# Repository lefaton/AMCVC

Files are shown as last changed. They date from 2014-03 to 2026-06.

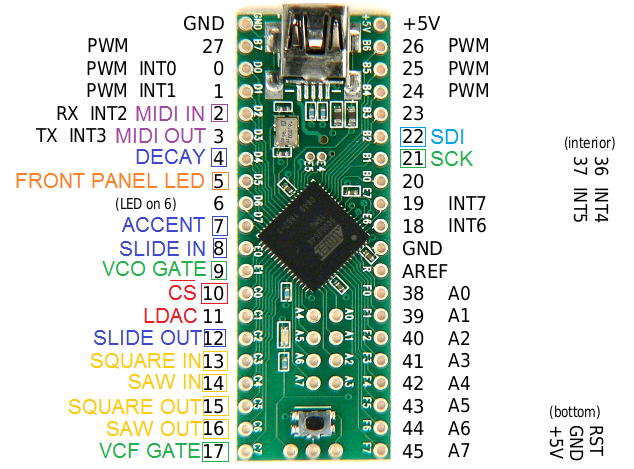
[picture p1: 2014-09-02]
Documents/Teensy 1.0++ pinout.png

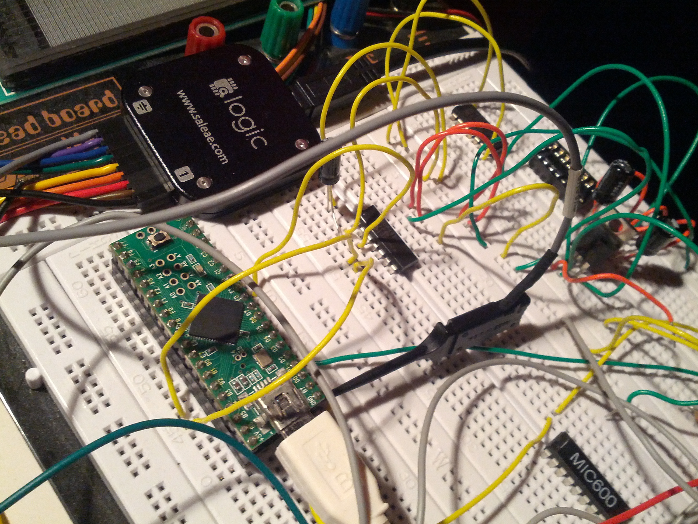
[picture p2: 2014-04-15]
Documents/Pictures/prototyping_phase3.jpg

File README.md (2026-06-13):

# AMCVC — Arduino MIDI to CV Converter

A MIDI-to-CV daughter board designed to drive the [x0x-heart](http://www.openmusiclabs.com/projects/x0x-heart/) — an open-source clone of the Roland TB-303 bass synthesizer engine. The board sits between a MIDI source and the x0x-heart, converting MIDI note and CC messages into analog control voltages (CV) and digital gate/control signals.

Built around a **Teensy++ 1.0** microcontroller and a **MCP4922 12-bit dual DAC** via SPI. The firmware is written as an Arduino sketch.

> **Status:** The firmware is working and was successfully tested on a prototype. The
> schematic and board netlist have been corrected (2026 revision) — the two changed nets
> (`~SHDN`, `~LDAC`) still need re-routing in Eagle plus a DRC pass before fabrication.

---

## Context — What Is the x0x-heart?

The [x0x-heart](http://www.openmusiclabs.com/projects/x0x-heart/) is an open hardware recreation of the Roland TB-303 synthesizer core. It exposes CV and gate inputs for pitch, filter cutoff, and a set of digital control lines (decay, accent, slide in, slide out) that replicate the 303's characteristic playing articulations.

The AMCVC board plugs into those inputs and translates MIDI messages into the signals the x0x-heart expects, making it possible to sequence and play the 303 engine from any standard MIDI controller or DAW.

---

## Hardware Overview

### Microcontroller — Teensy++ 1.0

The [Teensy++ 1.0](https://www.pjrc.com/teensy/) is a compact USB-capable AVR microcontroller board (AT90USB1286). It runs the Arduino-compatible MIDI library and handles SPI communication with the DAC. A reference pinout is included in `Documents/Teensy 1.0++ pinout.png`.

### DAC — MCP4922 (12-bit, dual-channel, SPI)

The [MCP4922](https://www.microchip.com/MCP4922) is a 12-bit dual-output DAC communicating over SPI. It provides two independent CV outputs:

| Channel | Purpose | Constant | Driven by |
|---|---|---|---|
| A (0) | VCO pitch | `VCO_DAC_ID = 0` | MIDI note number  |
| B (1) | VCF cutoff  | `VCF_DAC_ID = 1` | MIDI CC 74 |

SPI is configured MSB-first, SPI Mode 0. The 16-bit command word sent to the MCP4922 is:

```
Bit 15   : A/B   — channel select (0 = channel A / VCO, 1 = channel B / VCF)
Bit 14   : BUF   — input buffer (0 = unbuffered)
Bit 13   : /GA   — gain select (1 = 1× gain, 0–Vref)
Bit 12   : /SHDN — output enable (1 = active)
Bits 11–0: 12-bit DAC value
```

`WriteDAC(channel, value)` builds the word per channel: it ORs in `0x3000` (bits 13
and 12 → 1× gain, output active) and sets bit 15 from the channel argument, so both
the VCO (channel A) and VCF (channel B) outputs are addressable.

### MIDI Isolation — 6N138 Optocoupler

MIDI input is electrically isolated using a [6N138](Documents/Datasheets/6N138.pdf) high-speed optocoupler, following the standard MIDI electrical interface specification. This prevents ground loops between the MIDI source and the synth circuitry.

---

## Pin Assignments (Teensy++ 1.0)

| Pin | Direction | Function |
|-----|---|---|
| 2 | INPUT | MIDI input (via 6N138) |
| 4 | OUTPUT | Decay control (x0x-heart) |
| 5 | OUTPUT | Front panel LED |
| 6 | OUTPUT | Board LED |
| 7 | OUTPUT | Accent control (x0x-heart) |
| 8 | OUTPUT | Slide In control |
| 9 | OUTPUT | VCO Gate |
| 10  | OUTPUT | SPI CS (MCP4922 chip select) |
| 11  | OUTPUT | SPI LDAC (DAC latch) |
| 12  | OUTPUT | Slide Out control |
| 13  | INPUT | Square wave input (x0x) |
| 14  | INPUT | Saw wave input (x0x) |
| 15  | OUTPUT | Square wave output |
| 16  | OUTPUT | Saw wave output |
| 17  | OUTPUT | VCF Gate |

---

## MIDI Configuration

```cpp
const int MIDIChannel = 3;  // MIDI channel to listen on
```

The sketch listens on MIDI channel 3 only — `MIDI.begin(MIDIChannel)` filters out
all other channels at the library level. To change channel, edit this constant and
re-upload.

---

## MIDI Note to CV Conversion

### Pitch (VCO)

The firmware converts MIDI note numbers to a 12-bit DAC value using a linear mapping:

```cpp
const float VCO_CV_step     = 68.25;  // DAC counts per semitone
const int   MIDI_Min_Note   = 24;     // C1 (lowest accepted note)
const int   MIDI_Max_Note   = 84;     // C6 (highest accepted note)
const int   MIDI_Start_Offset = 24;   // note 24 maps to DAC value 0
const int   VCO_CV_Offset   = 0;      // global tuning offset in semitones
```

Conversion formula:

```
convertedVal = (note + VCO_CV_Offset - MIDI_Start_Offset) × VCO_CV_step
```

**Example values:**

| MIDI Note | Note Name | DAC value | Approx. CV |
|---|---|---|---|
| 24 | C1 | 0 | 0 V |
| 36 | C2 | 819 | ~1 V |
| 48 | C3 | 1638 | ~2 V |
| 60 | C4 (middle C) | 2457 | ~3 V |
| 72 | C5 | 3276 | ~4 V |
| 84 | C6 | 4095 | ~5 V |

The 60-semitone range (C1–C6) maps to 0–4095, giving **1V/octave** when the DAC reference voltage is 5V. Fine-tune `VCO_CV_step` if your VCO has a different V/oct scaling. The full lookup table is in `Documents/table_midi_cv.xlsx`.

### Gate

| MIDI event | Gate pins | Logic |
|---|---|---|
| Note On (velocity > 0)  | pin 9 + pin 17 | LOW (active)  |
| Note Off / velocity = 0 | pin 9 + pin 17 | HIGH (off) |

The x0x-heart gates are active-low. Both the VCO gate (pin 9) and VCF gate (pin 17)
are driven together.

### Note priority (monophonic note stack)

The firmware is monophonic but tracks held notes in a small stack (up to 8 notes):

- **Note On** pushes the note and plays it immediately (last-note priority).
- **Note Off** removes the note from the stack. Releasing a note that is *not* the
  one currently sounding does **not** cut the gate — it just leaves the stack.
- Releasing the sounding note falls back to the most recently held note still down;
  the gate only closes when no notes remain.

This makes legato/overlapping play behave the way a hardware mono synth does.

### VCF cutoff (CC 74)

MIDI **CC 74** (the standard "brightness"/cutoff controller) drives the VCF on DAC
channel B. Values 0–127 are mapped linearly to the full 12-bit range (0–4095).

---

## TB-303 Specific CC Messages

The x0x-heart exposes four articulation controls specific to the TB-303 playing style. The firmware maps MIDI CC messages to digital lines:

| CC  | Hex | Function | Effect when value > 100 |
|-----|---|---|---|
| 99  | 0x63  | Decay | Pin 4 LOW (decay enabled) |
| 100 | 0x64  | Accent | Pin 7 LOW (accent enabled) |
| 101 | 0x65  | Slide In | Pin 8 LOW (slide in enabled) |
| 102 | 0x66  | Slide Out  | Pin 12 LOW (slide out enabled) |

A CC value strictly above 100 (`triggerLimit = 0x64`) activates the control; 100 or
below deactivates it. CC 74 (cutoff) is the exception — it is a continuous value, not
a trigger (see [VCF cutoff](#vcf-cutoff-cc-74) above).

**Slide mutual exclusion:** Slide In and Slide Out are mutually exclusive — activating one automatically cancels the other, mirroring the 303's hardware behavior.

---

## Wave Pass-Through

The x0x-heart outputs both a **square wave** and a **sawtooth wave**. The AMCVC board reads these on pins 13/14 and re-outputs them on pins 15/16 every loop cycle, acting as a signal buffer:

```cpp
digitalWrite(sawWaveOut_Pin,    digitalRead(sawWaveIn_Pin));
digitalWrite(squareWaveOut_Pin, digitalRead(squareWaveIn_Pin));
```

---

## Repository Structure

```
sketch_MIDI_to_CV/
  sketch_MIDI_to_CV.ino       ← Arduino firmware (upload this to Teensy)

Documents/
  table_midi_cv.xlsx          ← Full MIDI note to CV conversion table
  Teensy 1.0++ pinout.png     ← Teensy++ 1.0 pin reference diagram
  x0x Heart - tb-303.fpd     ← Front panel design (Frontpanel Designer)
  x0xheartmanual.pdf          ← x0x-heart complete manual

  Eagle/
    *.sch   ← Circuit schematic (Eagle CAD) — use this as reference
    *.brd   ← PCB layout (Eagle CAD) ⚠️ 2 nets unrouted after netlist fix

  Datasheets/
    MCP4922.pdf               ← 12-bit dual DAC datasheet
    6N138.pdf                 ← MIDI optocoupler datasheet
```

> ⚠️ **PCB note:** The Eagle netlist bugs (`~SHDN` grounded, `~LDAC` floating) are fixed in
> both `.sch` and `.brd`. On the board these two nets are now **unrouted airwires** — open in
> Eagle, run ERC/forward-annotation, route `~SHDN` (→ +5V) and `~LDAC` (→ MCU pin 11), then DRC
> before sending to a fab.

---

## Setup

### Arduino Libraries Required

- **MIDI Library** — [FortySevenEffects/arduino_midi_library](https://github.com/FortySevenEffects/arduino_midi_library)
- **SPI** — built into the Arduino/Teensy core

### Upload Steps

1. Install [Teensyduino](https://www.pjrc.com/teensy/teensyduino.html)
2. Select board: **Teensy++ 1.0**
3. Set USB Type to **Serial** (for debug output)
4. Open `sketch_MIDI_to_CV/sketch_MIDI_to_CV.ino`
5. Upload

MIDI runs at 31250 baud on the hardware UART. Debug output runs at 57600 baud on USB Serial.

---

## Known Issues & Future Work

- **Two nets need routing** — after the 2026 netlist fixes, `~SHDN` and `~LDAC` are
  unrouted airwires on the board (see below); they must be routed in Eagle before a fab run
- **Monophonic only** — no chord support; the note stack gives last-note priority but a single voice
- **Firmware untested since revision** — the 2026 firmware changes (dual-channel DAC,
  VCF CC 74, note stack, channel filtering, non-blocking LED) have not yet been flashed
  and verified on hardware

### Fixed in the 2026 revision

**Schematic / PCB netlist** (corrected in both `.sch` and `.brd`, verified by netlist
re-parse — Eagle ERC/DRC still required):

- **DAC `~SHDN` no longer grounded** — pin 9 moved from `AGND` to `+5V`. It was tied to
  ground, which held both DAC outputs in permanent hardware shutdown (root cause of "no CV out")
- **DAC `~LDAC` now connected** — pin 8 wired to MCU pin 11; both were floating, so the
  latch line never transferred values to the outputs
- **VCF output labelled** — the `VOUTB` connector pad was renamed `UNUSED` → `VCF_CUTOFF`

> On the board, the two changed nets (`~SHDN`, `~LDAC`) are left as **airwires** — the old
> AGND copper at pad 9 was removed so nothing shorts. Open the `.brd` in Eagle, run
> ERC/forward-annotation, route the two airwires, then DRC.

**Firmware:**

- **VCF CV** — DAC channel B is now driven from MIDI CC 74
- **MIDI channel filtering** — `MIDI.begin(MIDIChannel)` replaces `MIDI_CHANNEL_OMNI`
- **Gate latency** — the LED blink is non-blocking, so Note On no longer delays the DAC write by 25 ms
- **Stuck-note edge cases** — a note stack prevents Note Off of an inactive note from cutting the gate

---

## License

GNU General Public License v2.0 — see [LICENSE](LICENSE).

If you use or build on this project, please mention [github.com/utopikprod](https://github.com/utopikprod/) as a reference.

---

## References

- [x0x-heart (Open Music Labs)](http://www.openmusiclabs.com/projects/x0x-heart/)
- [Teensy++ 1.0 (PJRC)](https://www.pjrc.com/teensy/)
- [MCP4922 datasheet](Documents/Datasheets/MCP4922.pdf)
- [6N138 optocoupler datasheet](Documents/Datasheets/6N138.pdf)
- [MIDI electrical specification](https://www.midi.org/specifications-old/item/midi-din-electrical-specification)

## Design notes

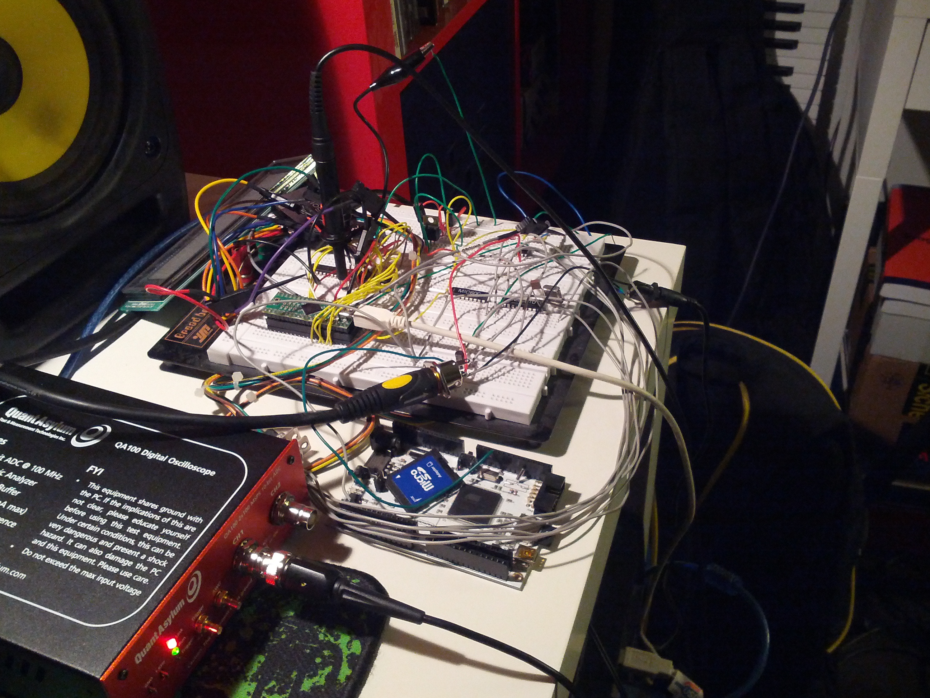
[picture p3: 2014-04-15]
Documents/Pictures/prototyping_phase2.jpg

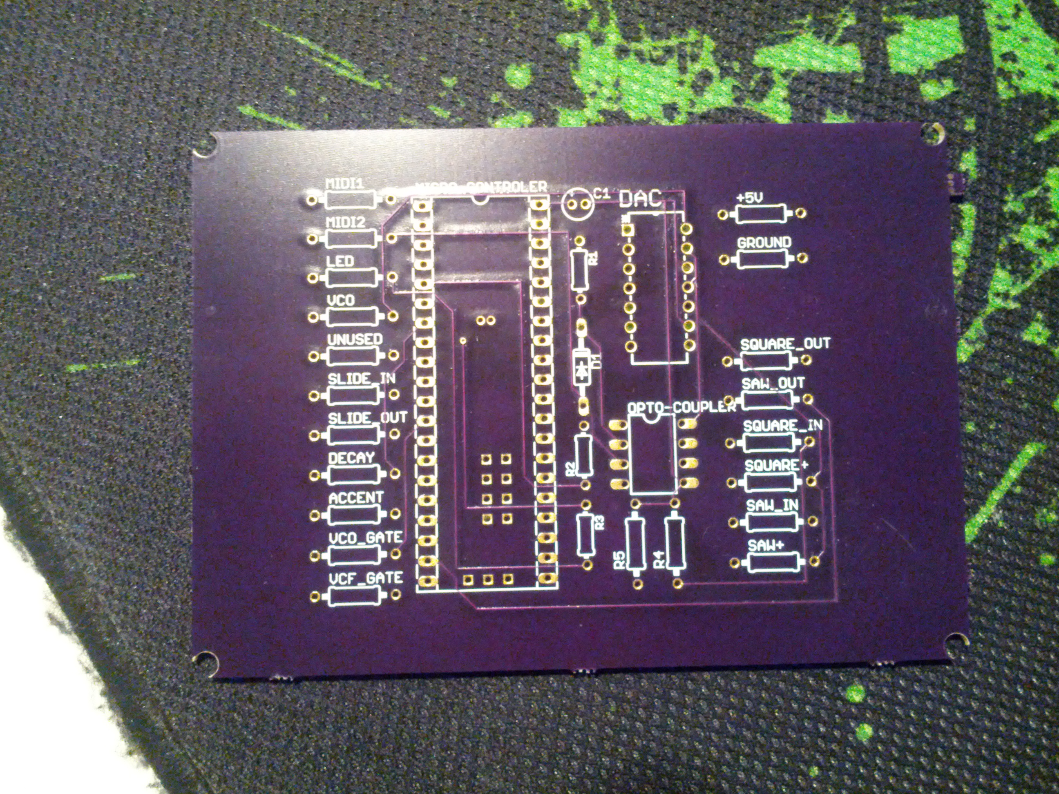
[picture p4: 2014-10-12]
Documents/Pictures/board_1.jpg

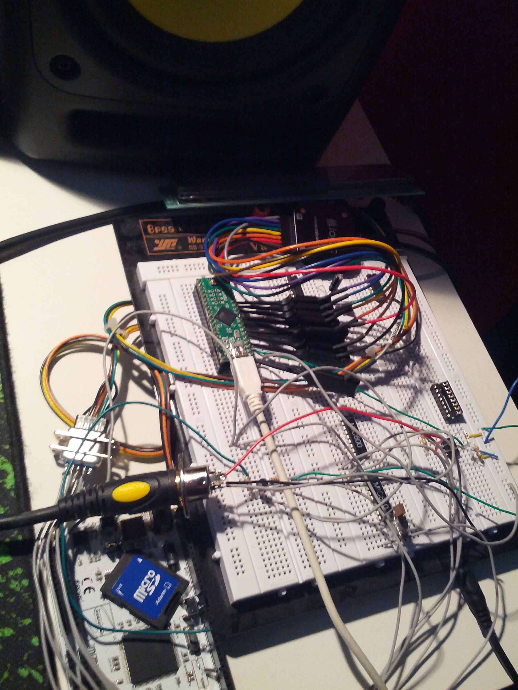
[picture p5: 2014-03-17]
Documents/Pictures/prototyping_phase1.jpg

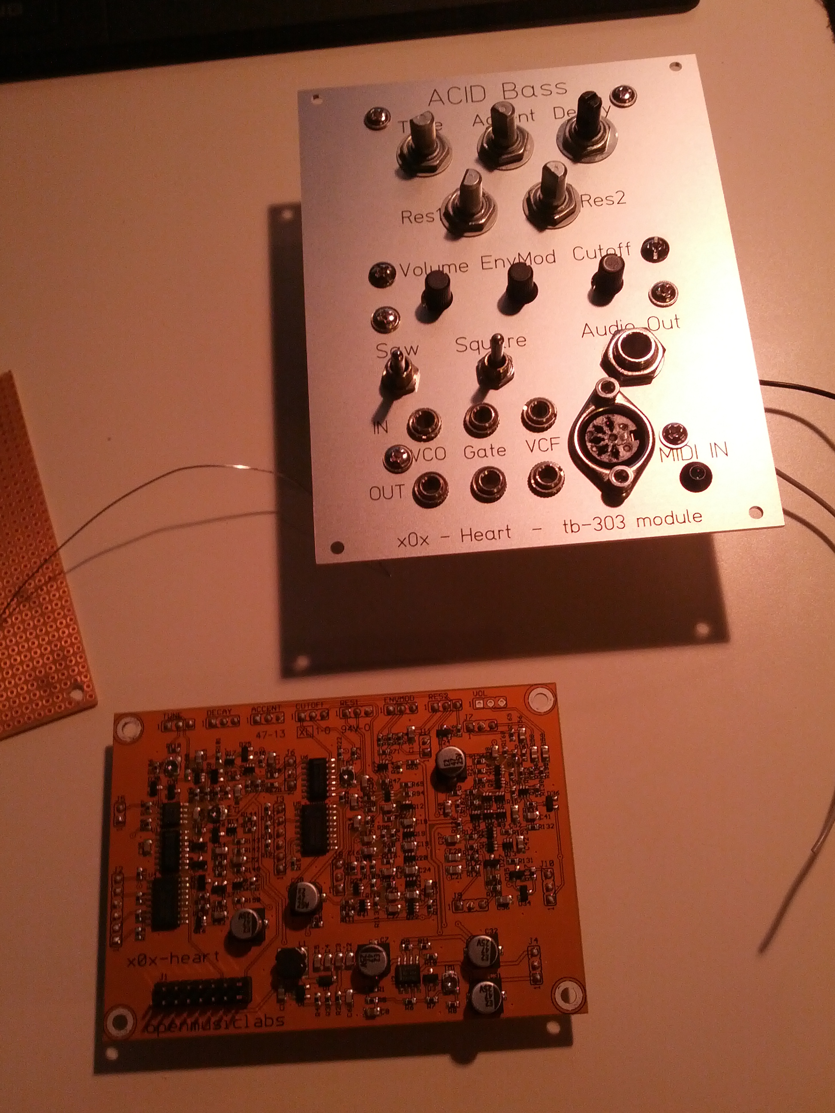
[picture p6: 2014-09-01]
Documents/Pictures/prototyping_phase4.jpg

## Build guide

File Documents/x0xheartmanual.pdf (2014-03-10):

# x0x-heart User Manual

Please read this document carefully before building up your synth. The x0x-heart does not come with any pots or control interface, so you will have to add parts to create a working synthesizer. It is possible to damage the x0x-heart if improper voltages are applied, so be sure to verify everything is in order before powering up your circuit. NOTE: power-supply voltage is 5VDC MAX!!

### 1. Overview:

Below is a picture of the x0x-heart board:

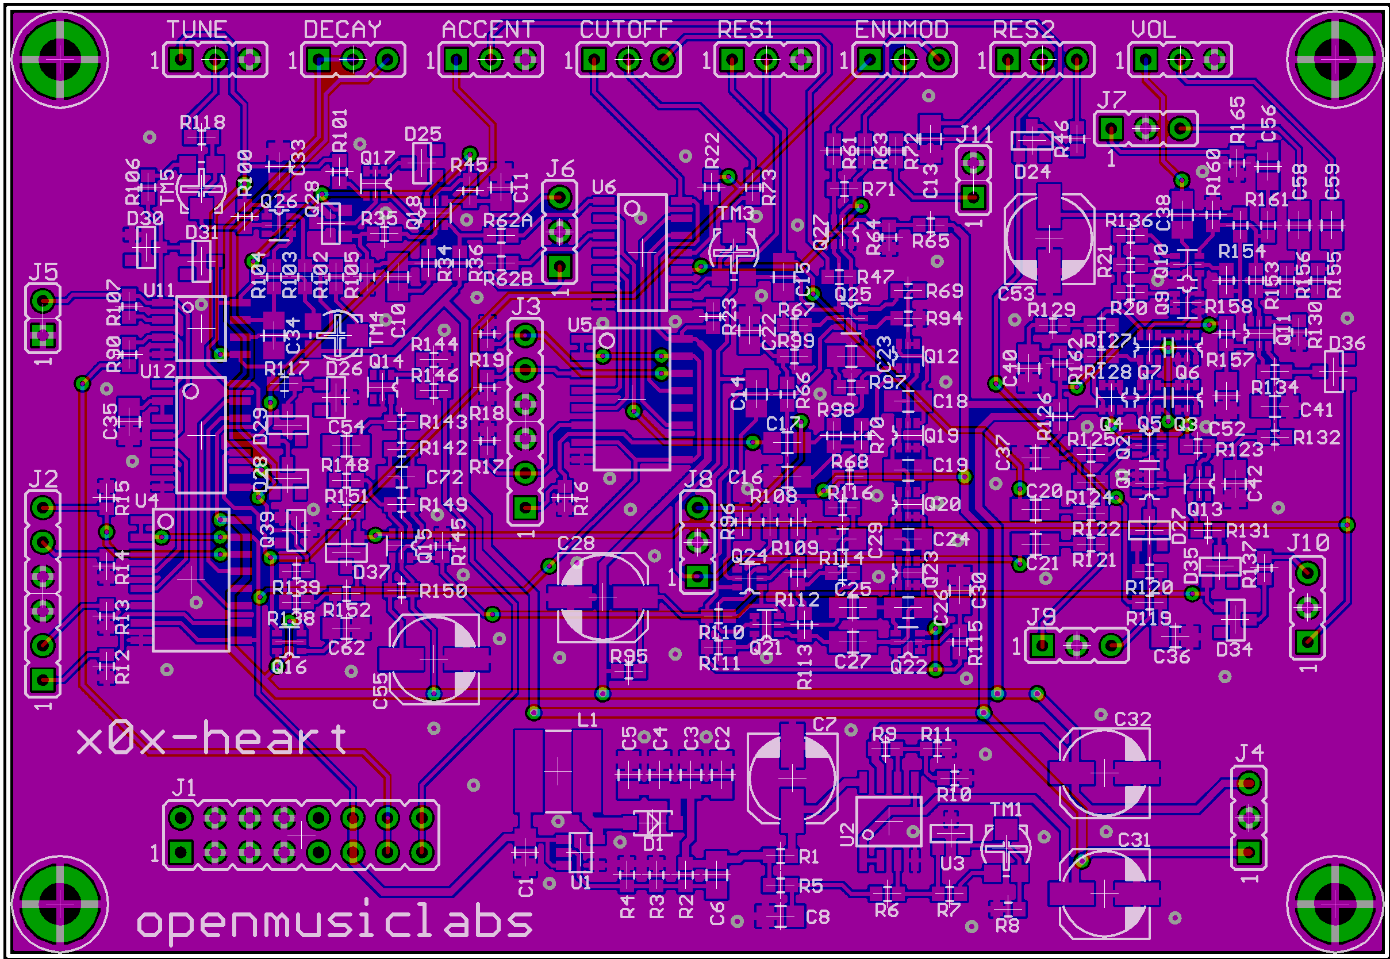
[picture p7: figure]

There are 8 headers for potentiometers, and 11 headers for control inputs and outputs. There are also 4 on-board potentiometers for tuning the power-supply, VCO, and VCF. The rest of this document will explain how to tune the x0x-heart, what all of the headers connect to, and how to interface with them. For all headers, pin1 has a square pad, and is labeled with a 1.

### 2. Tuning

The x0x-heart has 4 SMT trim pots, which require a small phillips screwdriver to adjust. TM1 adjusts the 5.333V supply, TM5 and TM4 adjust the VCO CV response, and TM3 adjusts the VCF cutoff frequency. These trim pots are meant to be turned a few times to get the setting right, and then left alone. They can only handle a few rotations, so do not use them as control inputs. These tuning procedures are best done after you have wired everything up, so that the operating currents are in their normal ranges. You should also let the x0x-heart warm up a bit before performing any calibration.

The 5.333V adjust was used on the original 303 to set the DAC control voltage for the VCO CV generator. Although this is not required on the x0x-heart, as CVs are not generated internally, the 5.333V supply determines how the x0x-heart sounds, so you are welcome to tune this to taste. To set it, turn TM1 while monitoring the output voltage on pin1 of J4 (5.333V is standard).

The x0x-heart uses a switching power-supply and resistive filter to replicate the 303 power-supply. And, just like the original, it sometimes droops under heavy load. Setting TM1 to 5.333V should cause only occasional drooping; going higher than that increases how often this happens, and going lower can eliminate it. The drooping only occurs on the 12V line, and usually only on accented notes. Adding extra circuitry which runs off the 12V line also increases the probability of this happening.

If the droop is not desired, solder a resistor in parallel with R4 and R3. A value between 47k and 100k should do the trick. The lower the resistor value, the less likely it will be to droop. Do not use a value below 12k, as this could hurt the regulator.

The VCO CV adjust is best done by first adjusting the CV width, and then adjusting the offset. This is usually set to 1V/octave, but can be set to any other value within the limits of the device. Set the TUNE knob to mid-position, and alternate between a 1V and 2V CV at the CV input (J1 - pin13,14), and monitor the audio output with an oscilloscope or guitar tuner. Adjust TM5 until the 1V and 2V signals produce tones that are exactly 1 octave apart. Next, adjust the CV offset by turning TM4 until a 2V signal produces a note 2 octaves below middle C (65.4Hz). Your x0x-heart should now be in tune.

The VCF cutoff adjust is a matter of taste. It modifies the exact range that the envelope modulation sweeps through. The 303 manual suggests setting it as follows: Set the CUTOFF knob to center, the waveform to saw, RES1 and RES2 knobs full clockwise, and the ENVMOD, DECAY, and ACCENT knobs full counterclockwise. Apply a 2V CV to the VCO (65.4Hz) and monitor the VCF output (J8 - pin1) on an oscilloscope. The ripples on the saw wave should be spaced at 2ms. If you don't have an oscilloscope, listen for a 500Hz tone on top of the 65.4Hz tone.

### 3. Potentiometers:

The potentiometers all have the 'top' of the pot at pin1, the wiper at pin2, and the 'bottom' at pin3. The 'top' is the side of the pot which is full clockwise. To find out which pins on your pot go where, turn the pot full clockwise, and measure the resistance between the wiper and the 2 other pins. One pin will measure the full resistance of the pot, and the other will measure 0ohms. The side which is 0ohms goes to pin1.

The following table lists the resistance values of the pots:

TUNE | 50kB
DECAY | 1MA
ACCENT | 50kB
CUTOFF | 50kA
RES1 | 50kB
ENVMOD | 50kA
RES2 | 50kB
VOL | 50kA

The only odd thing about the pots, is that the resonance pot is a dual pot. But, the 2 independent parts of the resonance pot are broken out to 2 different headers: RES1 and RES2. RES1 is the feedback pot in the filter, and controls the actual resonance. RES2 controls the amount the accent affects the cut-off frequency. If you are wiring these as 2 separate pots, you may choose to wire RES2 backwards, as turning RES2 more clockwise would normally decrease the affect the accent has on the cut-off frequency.

### 4. J1 - Eurorack header:

All of the pins are doubled up on the Eurorack header (i.e. pin1 and pin2 shorted, pin3 and pin4 shorted).

The following table lists the connections on Eurorack header:

pin1,2 | no connection
pin3,4 | ground
pin5,6 | ground
pin7,8 | ground
pin9,10 | no connection
pin11,12 | Power in, 5VDC MAX!!
pin13,14 | VCO CV in
pin15,16 | GATE in

The Power in connection goes straight to a switching power-supply. This input can work as low as 3.3VDC, and as high as 5VDC. The lower limit is actually set by the level shifter chips, which are not guaranteed to work below 3.3V (although will probably work at 3V). If you want to operate at lower voltages, you can cut some traces and power the level shifters from another bus. The voltage regulator can work down to 1.8VDC, but is not very reliable below 2.7VDC because the inductor and capacitors are optimized for 5VDC.

The high limit is set by the destructive voltage on the switching regulator (actually 6V, but best not to tempt fate). The switching regulator IC can be easily destroyed by over voltage, so be certain that there is no more than 5VDC on pin11 or pin12 of J1! Measure with a multimeter before connecting for the first time.

If you do not have a 5VDC supply, you can easily create one with a 7805 regulator. This will also act as input over-voltage protection. There is no input protection on the circuit as there wasn't a good way of doing this cheaply while keeping the input current consumption down. If you are running the x0x-heart off of a battery, you may want to put a high current diode in parallel or series with the input, to protect against reversed battery connections.

The x0x-heart consumes around 50mA from a 5V supply. This value goes up as the voltage goes down, so a 3V supply will require 85mA.

The VCO CV in connection goes through a 220k resistor to the slide/buffer circuitry. This can handle inputs from 0V to 12V, and is fairly tolerant of over/under-voltage conditions. The input can be tuned within a certain range, but is optimized for 1V/octave. CV inputs above 5V might start getting out of tune, as the original 303 was not designed for CVs above this range. The x0x-heart will normally not produce any sound unless there is a CV applied (the CV drifts out of range).

The Gate in connects to the base of transistor through a 22k resistor. It can accept 0V to 12V in, and is tolerant of over/under-voltage conditions. A 5V signal is preferred, as this is used in the original 303, and other voltages might affect the timing slightly (although probably not noticeably). A high level voltage turns on the gate, and 0V turns off the gate.

### 5. J2 - Digital control input 1:

This header controls the slide, accent, and decay circuitry. All of these pins are inputs, and are 12V tolerant. They are normally pulled low, so if there is no input connection, all of the controls will be off. The inputs go directly to the CD40109 level shifters, which use the Power in voltage as their logic level. Using a logic level lower than the Power in voltage is not guaranteed to work. You can use voltages higher than Power in, but the input pins will draw more current. You should only send digital signals to these pins, as slow transition times will cause the device to draw significantly more power, and might cause the x0x-heart to temporarily stop functioning.

pin1 | slide input control in
pin2 | slide output control in
pin3 | ground
pin4 | ground
pin5 | decay control in
pin6 | accent control in

The Slide input control in connects the slide capacitor to the input CV, and enables slid notes. A logic level high signal engages the slide, and 0V disengages the slide.

The Slide output control in connects the slide capacitor to the output of the CV buffer. This transfers the current CV level to the slide capacitor, so that new notes slide from the old value to the new one. A logic level high signal connects the capacitor, and 0V disengages the capacitor.

To replicate original 303 behaviour, these 2 slide signals must always be opposite of one another. So when one is high, the other must be a 0V, and vice-versa. The reason why this was not hard-wired this way, is that unique slide effects can be made by having independent control of the 2 slide lines. It is not advisable to turn both slide control inputs on at the same time. This will cause the CV buffer to become unstable and no longer respond to the input CV. The device probably won't be harmed under that condition, but it's not guaranteed.

One effect worth trying, is to only using the Slide input control, and pulse width modulate (PWM) the signal. This will engage the slide capacitor for a smaller percentage of the time, effectively increasing its value, and increasing the slide time. This slide time is then determined by the PWM value.

The Decay control in shorts out the DECAY pot, and reduces the decay time to its minimum value. A high level engages the short, and a 0V signal gives control back to the pot. Using a PWM signal on this control line will allow for digitally controlled decay times, as long as the DECAY pot is set to its longest value. In the 303, the decay control and accent control are tied together, so whenever accents are turned on, the decay time is also set to its minimum.

The Accent control in sends a replica of the VCF envelope to both the VCF and VCA, to give extra punch to accented notes. This goes through the ACCENT pot to set the accent amount. Again, using a PWM signal here will allow for digital control of the accent level.

### 6. J3 - Digital control input 2:

This header controls the waveform select, cutoff frequency, and envelope mod parameters. The same voltage conditions apply to this header as to J2, so review that section as necessary.

pin1 | square wave control in
pin2 | saw wave control in
pin3 | ground
pin4 | ground
pin5 | cutoff control in
pin6 | envmod control in

The Square wave control in determines whether the square wave is sent to the VCF/VCA circuitry. A high level logic signal enables the square wave, and a 0V signal disables the square wave.

The Saw wave control in determines whether the saw wave is sent to the VCF/VCA circuitry. A high level logic signal enables the saw wave, and a 0V signal disables the saw wave.

Both of the wave control signals can be PWM'd to change their amplitude. This could be used as another form of VCA control. They can also be modulated at slower rates to effectively LFO the VCO output, which is a pretty good effect. They can also be mixed together by turning both wave controls on at once, although since the square and saw are out of phase, this has the effect of eliminating the fundamental, and accentuating the higher harmonics.

The cutoff control in is a digital control line for setting the cutoff frequency. A high level signal sets the cut-off to its maximum value, and a 0V signal returns control to the CUTOFF pot. With the control signal engaged, the CUTOFF pot still has a small effect, and can be used to boost levels above what is attainable in a normal 303. PWM signals can be used to set the cut-off level anywhere between maximum, and whatever the CUTOFF pot is set to. As a result, this signal works best when the CUTOFF pot is set to minimum.

The Envmod control in is a digital signal line for setting the envelope modulation amount. A high level signal sets the modulation to its maximum level, and a 0V signal sets it to whatever the ENVMOD pot is set to. With the control signal engaged, the ENVMOD pot will still have a small effect, and can be used to boost levels above what is attainable in a normal 303. PWM signals can be used to set the modulation level anywhere between maximum and whatever the ENVMOD pot is set to. As a result, this signal works best when the ENVMOD pot is set to minimum.

### 7. J4 - Power out:

This header supplies the 5.333V and 12V from the x0x-heart power-supply for use in external circuits. Be careful about how much current you draw from these lines, as excess current will cause the x0x-heart to drift out of tune, or not function. The 303 was designed with a very weak power-supply, which is one of the keys to its unique sound. Altering how much current is drawn will alter the sound. A few milliamps is acceptable, but more than that might cause audible problems. These outputs are mostly for reference use. Be careful to not connect them to other voltage supplies, as that could damage the circuit.

pin1 | 5.333V out
pin2 | ground
pin3 | 12V out

### 8. J5 - VCO CV out

This header supplies the buffered VCO CV signal. It is post the slide circuitry, so the CV will be slid if enabled. The output is diode protected to ground and the 12V rail, but be careful to not connect the CV out to other voltage sources, as that could damage the circuit.

pin1 | ground
pin2 | VCO CV out

### 9. J6 - Waveform out

This header supplies the saw and square wave for external use. These signals are DC coupled! This means that the average voltage on these lines is over 5VDC, and damage can occur to other synths or to the x0x-heart if improperly connected. The reason why they are not AC coupled, is twofold: 1. it is uncertain what value of coupling capacitor would be appropriate for your application, and 2. you may not want it AC coupled for your application. But, for almost all applications you probably will want to AC couple the signal. This simply involves placing a capacitor from the output pin to your external circuit.

The voltage levels coming off the waveform out header are also not line level. They are approximately 5Vpp, which can damage some audio equipment. So, if you intend to send the signal to a mixing board or computer input, you will need to both AC couple, and attenuate the signal. A voltage divider of 100k/22k should do a good job of reducing the signal to line level. For modular synth usage, you might need to amplify the signal.

Be careful to not draw too much current from these pins, as it will effect the sound of the waveforms. only drive input impedances of 47k or greater (100k is preferred). You can probably go a little lower, but avoid it if possible.

pin1 | saw out
pin2 | ground
pin3 | square out

### 10. J7 - Mixer

The mixer header connects to the VCA output mixing circuitry. The inputs and outputs are very tolerant of over/under-voltage conditions.

pin1 | mix out
pin2 | ground
pin3 | mix in

The Mix out is the same as the mix out on the 303, and is an AC coupled signal, biased to ground, with a 1k output impedance. It is a line level signal.

The Mix in is the same as the mix in on the 303, and is AC coupled with an input impedance of 100k. It accepts line level signals.

### 11. J8 - VCF

The VCF header allows external audio signals to pass in and out of the VCF.

pin1 | VCF out
pin2 | ground
pin3 | VCF in

The VCF out signal comes directly from the 'top' of the RES1 pot, and is AC coupled to ground. It is a low level signal, a little less than line level, but has a very low output impedance. Be careful to not draw too much current from this pin, as it will effect the sound of the x0x-heart, and shorting it to other voltage sources could damage the x0x-heart. It is best to use at least a 1k resistor in series with this pin before sending it to other devices (for protection). If you are coupling it to a non-zero bias voltage, another AC coupling capacitor should be used.

The VCF in pin goes to the base of the differential pair on the VCF. This is the same point where the VCO enters the VCF. There is no input protection on these pins, and the signal will need to be AC coupled externally. Again, these parts are left off so that the final design can be optimized for your needs. The input is terminated with a 2.2k resistor to 5.333V. If you are sending in audio signals from a modular synth, a 220k resistor and 1uF capacitor in series with the input should be adequate to attenuate the signal and protect the input. For line level signals, a 47k resistor and a 1uF capacitor can be used. The smaller the resistor, the louder the sound will be. For all input signals, a series resistor is required.

### 12. J9 - VCA input

The VCA input header allows external audio signals to be passed through the VCA, and also allows control of the amplitude of the VCA.

pin1 | VCA audio in
pin2 | ground
pin3 | VCA control in

The VCA Audio in connects directly to the base of the differential pair on the VCA, and is the same point where the VCF signal enters. There is no input protection on these pins, and the signal will need to be AC coupled externally. Again, these parts are left off so that the final design can be optimized for your needs. The input is terminated with a 2.2k resistor to 5.333V. If you are sending in audio signals from a modular synth, a 1M resistor and 0.1uF capacitor in series with the input should be adequate to attenuate the signal and protect the input. For line level signals, a 220k resistor and a 1uF capacitor can be used. The smaller the resistor, the louder the sound will be. For all input signals, a series resistor is required.

The VCA control in connects to the control point on the VCA, and is best modeled as a diode to ground. The envelope and accent signals also enter at this point, so care must be taken to not affect how those signals behave. The easiest input to construct is to just use a 220k resistor in series with the input. This will allow 12V to turn on the VCA fully, and 0V to shut it off. But, this resistor will also absorb some current from the normal control sources, so a series diode should be used (just as with the accent signal via R120 and D27). The only drawback to using the diode, is that the control will be nonlinear for inputs voltages below 1.2V. Without the diode its nonlinear for voltages below 0.6V.

fundamentally, the VCA control in is not a CV, and instead a current controlled input. For accurate CV control, a voltage to current converter circuit needs to be used. The simplest form of this is just a PNP transistor with a 220k resistor from the emitter to 12V, and the collector going to the VCA control point. This is the same circuit used in the 303 for the envelope control via Q31 (Q13B in the x0x-heart). To get good linearity, and correct the polarity, an op-amp can be used to provided feedback around this transistor.

### 13. J10 - Gate out

The Gate out header supplies a 12V version of the gate signal, and a 12V trigger signal which is used to trigger the internal envelope generators.

pin1 | trigger out
pin2 | ground
pin3 | gate out

The Trigger out signal comes from the collector of Q15B, and is used internally in the x0x-heart to trigger the VCF and VCA envelopes. Be careful not to apply any voltages to this pin. It will need to be externally buffered before being used by other circuitry, to protect the x0x-heart. An easy way of doing this would be to send the output to 4000 series logic running from a 12V rail. This is a digital signal, which gives a short pulse (~1.5ms) every time the gate input signal is pulled high.

The Gate out signal comes from the collector of Q15A, and is protected with a 1k resistor and diode in series with the output. This is a replica of the gate out signal on the 303. The output is fairly tolerant of under/over-voltage conditions, but will prevent the x0x-heart from functioning if shorted to ground, or to a voltage supply. if you are sending this signal to a buffer, be sure to tie it to ground via a 100k resistor as the diode will prevent the signal from ever going low, once it has been pulled high.

### 14. J11 - VCF cutoff control

The VCF cutoff control header allows for external analog control of the VCF cutoff frequency. This signal goes directly to the base of Q27B (the envelope modulation input point), so care must be taken to buffer any input signals properly to protect the transistor. A 100k resistor in series should work well for most applications. A smaller resistor will increase the effect of a given control voltage. If you only intend to use audio signals to modify the cutoff frequency, it is advisable to AC couple the signal with a 1uF capacitor in series with the resistor.

This control point is biased up to 3V internally, so you will need apply a 3V signal to achieve no cutoff change. Signals below 3V will decrease the cutoff frequency, and above 3V will increase the cutoff frequency. Connecting a 330k resistor from the VCF control point to 12V can adjust this bias so that signals below 0V move the filter down, and those above 0V move the filter up.

pin1 | VCF cutoff control in
pin2 | ground

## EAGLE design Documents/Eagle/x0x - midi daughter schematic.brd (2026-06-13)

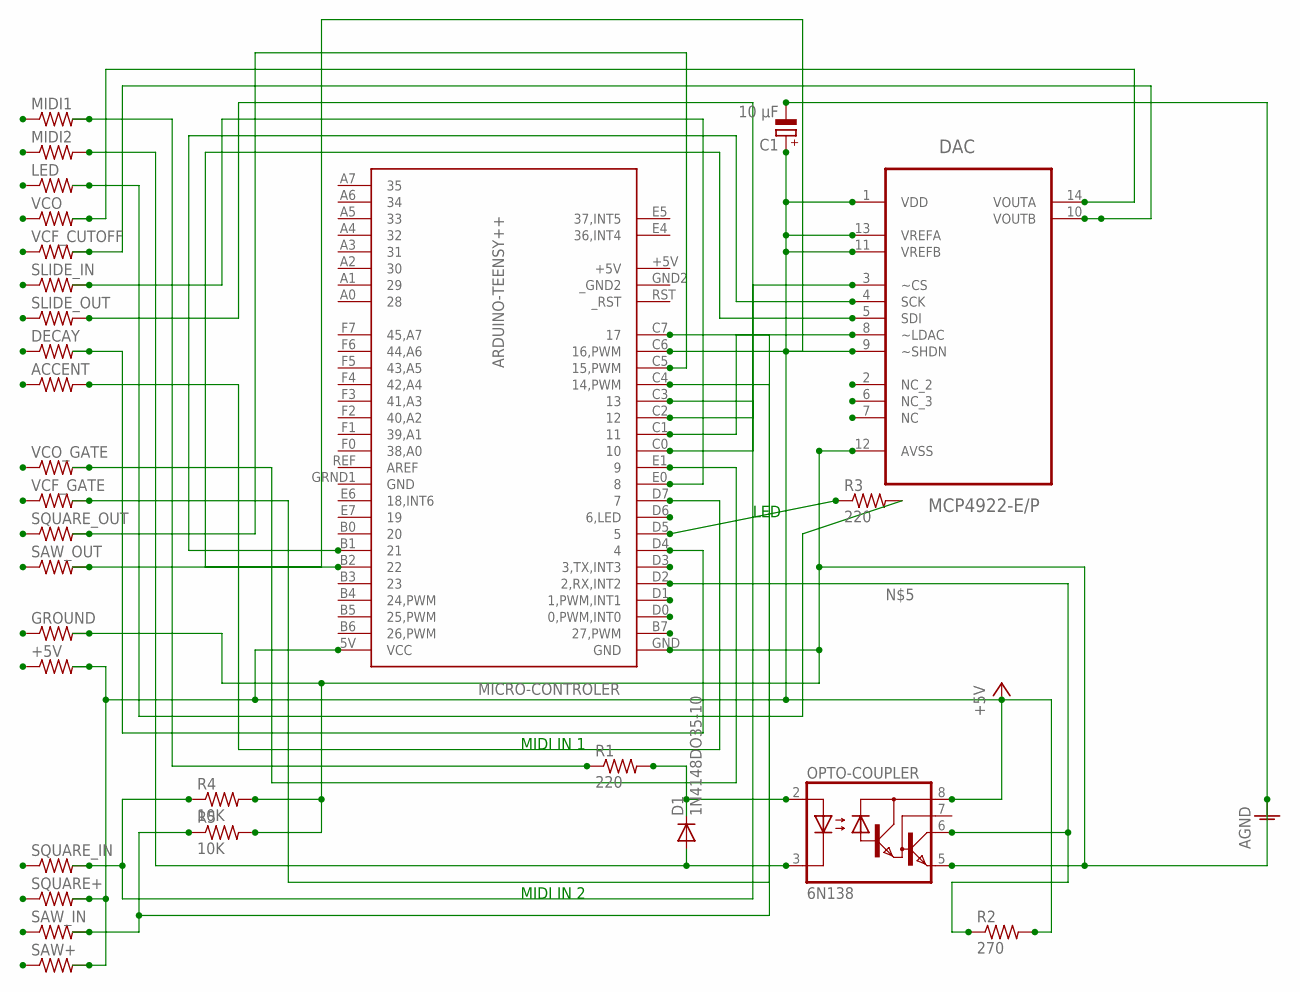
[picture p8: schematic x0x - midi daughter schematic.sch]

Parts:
+5V: R-US_0207/10; 0207/10
ACCENT: R-US_0207/10; 0207/10
C1: 10 µF; E1,8-4
D1: 1N4148DO35-10; DO35-10
DAC: MCP4922-E/P; DIP254P762X533-14
DECAY: R-US_0207/10; 0207/10
GROUND: R-US_0207/10; 0207/10
LED: R-US_0207/10; 0207/10
MICRO-CONTROLER: ARDUINO-TEENSY++; TEENSY++
MIDI1, MIDI2: R-US_0207/10; 0207/10
OPTO-COUPLER: 6N138; DIL08
R1, R3: 220; 0204/7
R2: 270; 0204/7
R4, R5: 10K; 0207/10
SAW+: R-US_0207/10; 0207/10
SAW_IN: R-US_0207/10; 0207/10
SAW_OUT: R-US_0207/10; 0207/10
SLIDE_IN: R-US_0207/10; 0207/10
SLIDE_OUT: R-US_0207/10; 0207/10
SQUARE+: R-US_0207/10; 0207/10
SQUARE_IN: R-US_0207/10; 0207/10
SQUARE_OUT: R-US_0207/10; 0207/10
VCF_CUTOFF: R-US_0207/10; 0207/10
VCF_GATE: R-US_0207/10; 0207/10
VCO: R-US_0207/10; 0207/10
VCO_GATE: R-US_0207/10; 0207/10

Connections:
+5V: +5V.2, C1.+, DAC.1 (VDD), DAC.9 (~SHDN), DAC.11 (VREFB), DAC.13 (VREFA), MICRO-CONTROLER.5V (VCC), MICRO-CONTROLER.+5V, OPTO-COUPLER.8 (VCC), R2.2, SAW+.2, SQUARE+.2
AGND: C1.-, DAC.12 (AVSS), GROUND.2, MICRO-CONTROLER.GND, OPTO-COUPLER.5 (GND), R4.2, R5.2
GND: MICRO-CONTROLER.GRND1 (GND)
unnamed: DAC.4 (SCK), MICRO-CONTROLER.B1 (21)
unnamed: DAC.5 (SDI), MICRO-CONTROLER.B2 (22)
unnamed: DAC.3 (~CS), MICRO-CONTROLER.C0 (10)
unnamed: D1.A, MIDI2.2, OPTO-COUPLER.3 (C)
unnamed: MICRO-CONTROLER.D2 (2,RX,INT2), OPTO-COUPLER.6 (VO), R2.1
unnamed: D1.C, OPTO-COUPLER.2 (A), R1.2
unnamed: MICRO-CONTROLER.D5 (5), R3.1
unnamed: MIDI1.2, R1.1
unnamed: MICRO-CONTROLER.C2 (12), SLIDE_OUT.2
unnamed: LED.2, R3.2
unnamed: DAC.14 (VOUTA), VCO.2
unnamed: DAC.10 (VOUTB), VCF_CUTOFF.2
unnamed: MICRO-CONTROLER.E0 (8), SLIDE_IN.2
unnamed: DECAY.2, MICRO-CONTROLER.D4 (4)
unnamed: ACCENT.2, MICRO-CONTROLER.D7 (7)
unnamed: MICRO-CONTROLER.E1 (9), VCO_GATE.2
unnamed: MICRO-CONTROLER.C7 (17), VCF_GATE.2
unnamed: MICRO-CONTROLER.C3 (13), R4.1, SQUARE_IN.2
unnamed: MICRO-CONTROLER.C4 (14,PWM), R5.1, SAW_IN.2
unnamed: MICRO-CONTROLER.C5 (15,PWM), SQUARE_OUT.2
unnamed: MICRO-CONTROLER.C6 (16,PWM), SAW_OUT.2
unnamed: DAC.8 (~LDAC), MICRO-CONTROLER.C1 (11)
_GND2: MICRO-CONTROLER.GND2 (_GND2)

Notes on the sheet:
LED
MIDI IN 1
MIDI IN 2

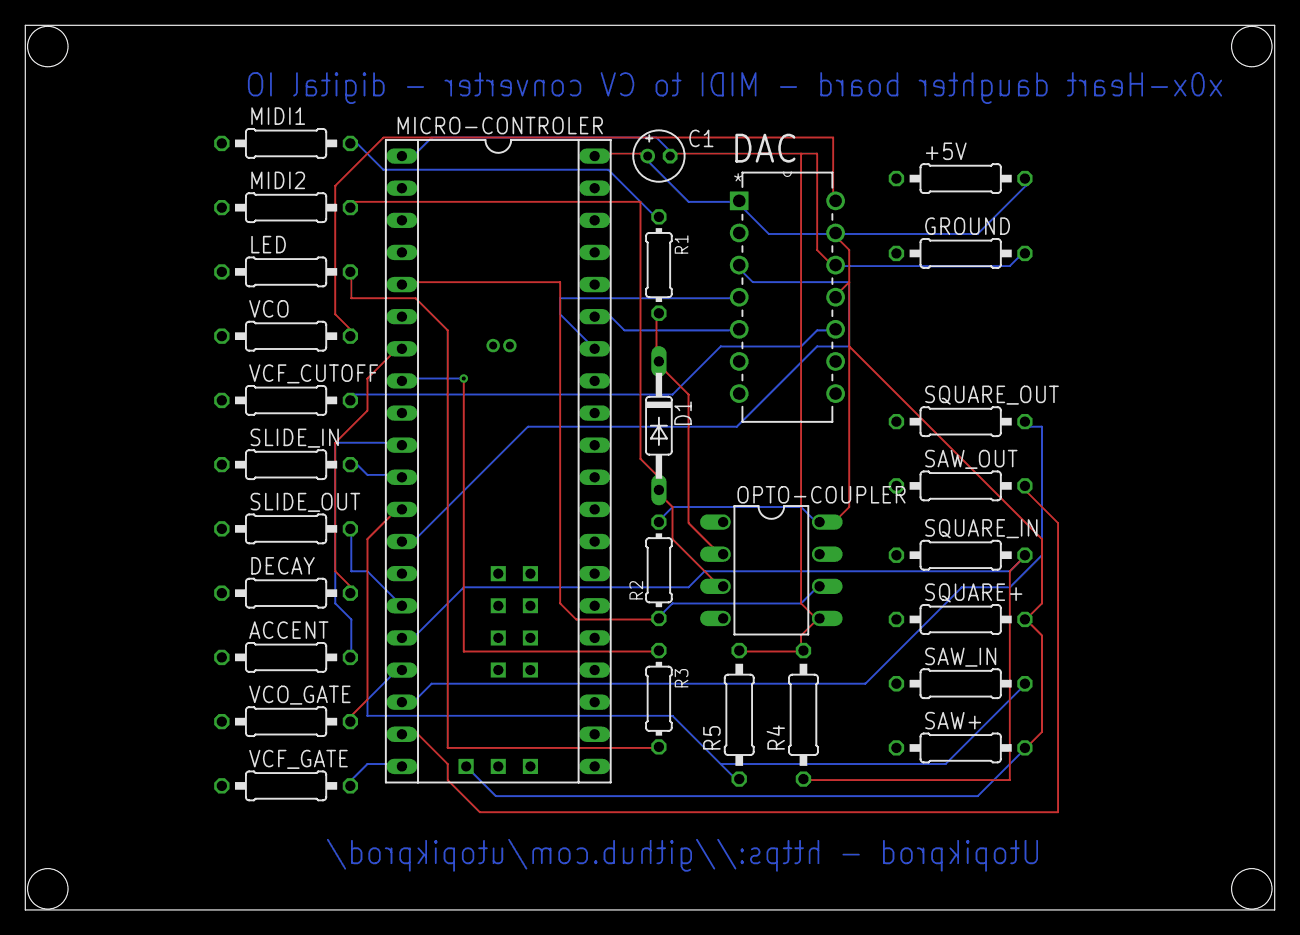
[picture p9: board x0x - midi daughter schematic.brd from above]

Board: 2 copper layers, 98.8 x 69.9 mm, 29 parts (0 on the bottom side), 24 nets.

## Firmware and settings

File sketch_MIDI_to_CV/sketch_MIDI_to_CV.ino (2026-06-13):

/*
Get MIDI messages and transform them into 12-bit DAC values driving the x0x-heart.
By Utopikprod
2014 - revised 2026

Changes in this revision:
 - MCP4922 word is now built per-channel, so channel B (VCF) actually works.
 - VCF cutoff is driven from MIDI CC 74 (standard "brightness"/cutoff).
 - Note On no longer blocks on the LED blink (non-blocking, millis()-based).
 - Monophonic note stack: releasing a non-active note no longer cuts the gate.
 - MIDI input is filtered to MIDIChannel instead of OMNI.
 - Dead code removed (shadowed `type`, unused Uart, stray PIN_D2/PIN_D3).
*/

#include <MIDI.h>
#include <SPI.h>

//MIDI channel used (1-16)
const int MIDIChannel = 3;

//CV VCO tuning
const int   VCO_CV_Offset    = 0;       // global tuning offset in semitones
const float VCO_CV_step      = 68.25;   // DAC counts per semitone
const int   MIDI_Min_Note    = 24;      // C1 (lowest accepted note)
const int   MIDI_Max_Note    = 84;      // C6 (highest accepted note)
const int   MIDI_Start_Offset = 24;     // note 24 maps to DAC value 0

//const IO variables
const int midiInput_Pin     = 2;
const int led_Pin           = 6;
const int frontPanelLed_Pin = 5;

//x0x heart digital control
const int decay_Pin    = 4;
const int accent_Pin   = 7;
const int slideIn_Pin  = 8;
const int slideOut_Pin = 12;
boolean slideIn  = false;
boolean slideOut = false;

const int squareWaveIn_Pin  = 13;
const int sawWaveIn_Pin     = 14;
const int squareWaveOut_Pin = 15;
const int sawWaveOut_Pin    = 16;

//MCP4922 DAC control
const int CS_Pin   = 10;
const int LDAC_Pin = 11;

const int VCO_DAC_ID = 0;   // MCP4922 channel A
const int VCF_DAC_ID = 1;   // MCP4922 channel B

const int VCO_Gate_Pin = 9;
const int VCF_Gate_Pin = 17;

//x0x heart specific control (MIDI CC numbers)
const byte decayCC    = 0x63;  // CC 99
const byte accentCC   = 0x64;  // CC 100
const byte slideInCC  = 0x65;  // CC 101
const byte slideOutCC = 0x66;  // CC 102
const byte cutoffCC   = 0x4A;  // CC 74  -> VCF cutoff (DAC channel B)

const byte triggerLimit = 0x64; // CC value must be > 100 to activate a control

int note, velocity, channel, d1, d2;

//Monophonic note stack (last-note priority)
const int MAX_NOTES = 8;
byte noteStack[MAX_NOTES];
int  noteCount = 0;

//Non-blocking LED blink state
boolean ledOn = false;
unsigned long ledOffAt = 0;

void setup()
{
  // Filter MIDI to the configured channel instead of listening to everything.
  MIDI.begin(MIDIChannel);

  SPI.begin();
  SPI.setBitOrder(MSBFIRST);
  SPI.setDataMode(SPI_MODE0);

  Serial.begin(57600);

  pinMode(led_Pin,           OUTPUT);
  pinMode(frontPanelLed_Pin, OUTPUT);
  pinMode(decay_Pin,         OUTPUT);
  pinMode(accent_Pin,        OUTPUT);
  pinMode(slideIn_Pin,       OUTPUT);
  pinMode(slideOut_Pin,      OUTPUT);

  pinMode(squareWaveOut_Pin, OUTPUT);
  pinMode(sawWaveOut_Pin,    OUTPUT);
  pinMode(squareWaveIn_Pin,  INPUT);
  pinMode(sawWaveIn_Pin,     INPUT);

  pinMode(midiInput_Pin, INPUT);

  pinMode(CS_Pin,   OUTPUT);
  pinMode(LDAC_Pin, OUTPUT);

  pinMode(VCO_Gate_Pin, OUTPUT);
  pinMode(VCF_Gate_Pin, OUTPUT);

  // Idle state: LEDs on, controls inactive (active-low), gates off (active-low).
  digitalWrite(led_Pin,      HIGH);
  digitalWrite(decay_Pin,    HIGH);
  digitalWrite(accent_Pin,   HIGH);
  digitalWrite(slideIn_Pin,  HIGH);
  digitalWrite(slideOut_Pin, HIGH);
  digitalWrite(VCO_Gate_Pin, HIGH);
  digitalWrite(VCF_Gate_Pin, HIGH);
}

// Build and send a 16-bit MCP4922 command word for the given channel.
//   bit15 A/B (0=A, 1=B), bit14 BUF=0, bit13 /GA=1 (1x gain), bit12 /SHDN=1 (active)
void WriteDAC(int dacChannel, int value)
{
  value = constrain(value, 0, 4095);
  unsigned int command = ((unsigned int)(dacChannel & 0x1) << 15)
                       | 0x3000                        // /GA + /SHDN
                       | (value & 0x0FFF);

  digitalWrite(LDAC_Pin, HIGH);
  digitalWrite(CS_Pin,   LOW);   // begin transfer

  SPI.transfer(highByte(command));
  SPI.transfer(lowByte(command));

  digitalWrite(CS_Pin,   HIGH);  // end transfer
  digitalWrite(LDAC_Pin, LOW);   // latch outputs
}

// Set the VCO pitch CV for a MIDI note and open the gate (active-low).
void playNote(byte n)
{
  int midiNote = constrain(n + VCO_CV_Offset, MIDI_Min_Note, MIDI_Max_Note);
  int convertedVal = (int)((float)(midiNote - MIDI_Start_Offset) * VCO_CV_step);

  WriteDAC(VCO_DAC_ID, convertedVal);

  digitalWrite(VCO_Gate_Pin, LOW);
  digitalWrite(VCF_Gate_Pin, LOW);

  Serial.print("Play note ");
  Serial.print(n);
  Serial.print(" -> DAC ");
  Serial.println(convertedVal);
}

void removeFromStack(byte n)
{
  int idx = -1;
  for (int i = 0; i < noteCount; i++)
  {
    if (noteStack[i] == n) { idx = i; break; }
  }
  if (idx < 0) return;
  for (int i = idx; i < noteCount - 1; i++) noteStack[i] = noteStack[i + 1];
  noteCount--;
}

void handleNoteOn(byte n)
{
  removeFromStack(n);                                  // avoid duplicates
  if (noteCount < MAX_NOTES) noteStack[noteCount++] = n;
  playNote(n);
  triggerLED();
}

void handleNoteOff(byte n)
{
  boolean wasActive = (noteCount > 0 && noteStack[noteCount - 1] == n);
  removeFromStack(n);

  if (noteCount == 0)
  {
    // No notes held: close the gates.
    digitalWrite(VCO_Gate_Pin, HIGH);
    digitalWrite(VCF_Gate_Pin, HIGH);
  }
  else if (wasActive)
  {
    // The sounding note was released: fall back to the most recent held note.
    playNote(noteStack[noteCount - 1]);
  }
}

void handleControlChange(byte ccNumber, byte ccValue)
{
  if (ccNumber == cutoffCC)
  {
    // Map CC 74 (0-127) to the full 12-bit VCF cutoff range on DAC channel B.
    int val = map(ccValue, 0, 127, 0, 4095);
    WriteDAC(VCF_DAC_ID, val);
    return;
  }

  if (ccNumber == decayCC)
  {
    digitalWrite(decay_Pin, ccValue > triggerLimit ? LOW : HIGH);
  }

  if (ccNumber == accentCC)
  {
    digitalWrite(accent_Pin, ccValue > triggerLimit ? LOW : HIGH);
  }

  if (ccNumber == slideInCC)
  {
    if (ccValue > triggerLimit)
    {
      if (slideOut) { slideOut = false; digitalWrite(slideOut_Pin, HIGH); }
      slideIn = true;
      digitalWrite(slideIn_Pin, LOW);
    }
    else
    {
      slideIn = false;
      digitalWrite(slideIn_Pin, HIGH);
    }
  }

  if (ccNumber == slideOutCC)
  {
    if (ccValue > triggerLimit)
    {
      if (slideIn) { slideIn = false; digitalWrite(slideIn_Pin, HIGH); }
      slideOut = true;
      digitalWrite(slideOut_Pin, LOW);
    }
    else
    {
      slideOut = false;
      digitalWrite(slideOut_Pin, HIGH);
    }
  }
}

// Non-blocking front-panel/board LED blink.
void triggerLED()
{
  digitalWrite(frontPanelLed_Pin, LOW);
  digitalWrite(led_Pin,           LOW);
  ledOn = true;
  ledOffAt = millis() + 25;
}

void updateLED()
{
  // Subtraction handles the millis() rollover correctly.
  if (ledOn && (long)(millis() - ledOffAt) >= 0)
  {
    digitalWrite(frontPanelLed_Pin, HIGH);
    digitalWrite(led_Pin,           HIGH);
    ledOn = false;
  }
}

void loop()
{
  // Wave pass-through buffer (square + saw).
  digitalWrite(sawWaveOut_Pin,    digitalRead(sawWaveIn_Pin));
  digitalWrite(squareWaveOut_Pin, digitalRead(squareWaveIn_Pin));

  updateLED();

  if (MIDI.read())
  {
    byte type = MIDI.getType();
    switch (type)
    {
      case NoteOn:
        note     = MIDI.getData1();
        velocity = MIDI.getData2();
        channel  = MIDI.getChannel();
        if (velocity > 0)
        {
          Serial.println(String("Note On:  ch=") + channel + ", note=" + note + ", velocity=" + velocity);
          handleNoteOn(note);
        }
        else
        {
          // Note On with velocity 0 is a Note Off.
          handleNoteOff(note);
        }
        break;

      case NoteOff:
        note     = MIDI.getData1();
        velocity = MIDI.getData2();
        channel  = MIDI.getChannel();
        handleNoteOff(note);
        break;

      case ControlChange:
        note     = MIDI.getData1();   // CC number
        velocity = MIDI.getData2();   // CC value
        channel  = MIDI.getChannel();
        handleControlChange(note, velocity);
        break;

      default:
        d1 = MIDI.getData1();
        d2 = MIDI.getData2();
        break;
    }
  }
}

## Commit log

2014-03-04 First Arduino handling since a while
    I tried some examples, I needed a reminder about MIDI norm for see how
    to implement the converter.
2014-03-10 Add DAC doc and code
    Continue with untested code. I will have to test many electronic things
    concerning timing issues before to continue.
    [sketch_MIDI_to_CV.ino]
2014-03-11 Electronic schematics
    I did the electronic MIDI input with 6N138 optocoupler and started
    design around 74HC595 replacing the MIC810 for now
2014-03-15 Replace serial by UART
    [sketch_MIDI_to_CV.ino]
2014-03-15 Use shiftOut() function add LSB pin for DAC
    shiftOut() function is a native arduino function for 74HC595 shift
    register, which does the same that I did for send bits one by one
2014-03-17 Fix DAC output bug
    [sketch_MIDI_to_CV.ino]
2014-03-18 First EAGLE draft
    [x0x - midi daughter schematic.brd, x0x - midi daughter schematic.sch]
2014-03-26 Use MIDI lib for read input data
    Code refactor using the MIDI lib, because of some synchronous problems.
    Also removed buffering concept (useless).
    [sketch_MIDI_to_CV.ino]
2014-03-31 Remove 74HC595 from the schematic
    I removed the 74HC595, because it doesn't really help since I have
    enough pin on the board. But it worked and it was interresting to see
    how to use it. Also they are some bugfix.
    [sketch_MIDI_to_CV.ino]
2014-04-01 Adapte MIDI range to tb-303 CV range
    [table_midi_cv.xlsx]
2014-04-15 Fix last electronic issue
    Updated few documents
    [x0x - midi daughter schematic.brd, x0x - midi daughter schematic.sch]
2014-09-01 Add EAGLE components
    [x0x - midi daughter schematic.brd]
2014-09-02 Add missing digital controls for x0x
    Added some code, pinout draw updated and few components added on EAGLE
    [x0x - midi daughter schematic.sch]
2014-09-02 Handle correctly slide in / slide out
    [sketch_MIDI_to_CV.ino]
2014-09-15 Finalise PCB
    Finish PCB v 1.0
    [x0x - midi daughter schematic.sch]
2014-10-12 Add board picture
2026-05-30 docs: rewrite README with full hardware details, pin table, MIDI-CV math and CC mapping
2026-06-13 Fix DAC shutdown/latch wiring, revise firmware, document changes
    Schematic (.sch) — netlist corrections (verified by re-parse, ERC/DRC
    still required in Eagle):
    - MCP4922 ~SHDN (pin 9) moved from AGND to +5V. It was tied to ground,
    which holds both DAC outputs in permanent hardware shutdown.
    - ~LDAC (pin 8) now wired to MCU pin 11; both were floating stubs, so
    the DAC latch line was never connected.
    - VOUTB connector pad renamed UNUSED -> VCF_CUTOFF (.sch + .brd) to
    document the VCF cutoff output intent.
    NOTE: board copper was intentionally NOT hand-edited — moving the ~SHDN
    net while leaving old traces would short +5V to GND. The .brd is left
    for Eagle to reconcile (ERC -> forwar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
    [x0x - midi daughter schematic.brd, x0x - midi daughter schematic.sch]
2026-06-13 Make board netlist consistent with fixed schematic; update PCB notes
    Board (.brd) — bring the netlist in line with the corrected schematic, as a
    clean ECO (no shorts, two nets left as airwires for re-routing in Eagle):
    - ~SHDN (DAC pad 9) moved from AGND to +5V signal.
    - Removed the AGND copper that reached pad 9 (no ground pour exists), so the
    pad is fully isolated and becomes an unrouted airwire instead of a short.
    - ~LDAC merged: MCU pin 11 (pad C1) added to the DAC pad-8 net; old N$45 removed.
    - AVSS (pad 12) copper left intact.
    Verified by re-parse: .brd netlist now matches .sch (~SHDN in +5V, AVSS in
    AGND, ~LDAC = DAC.8 + MICRO.C1), and no copper touches pad 9.
    README: PCB notes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
    [x0x - midi daughter schematic.brd]
2026-06-13 Remove dangling AGND stub near DAC pad 9 on the board
    Left over after isolating ~SHDN from AGND: a 7.62 mm AGND track ended in
    mid-air at (62.23,46.99). AVSS stays connected via the (63.5,53.34) node,
    so the stub was pure dead copper. Verified with KiCad DRC (kicad-cli pcb
    import --format eagle + drc): the track_dangling violation is gone and the
    only remaining unconnected items are the two intended airwires (~SHDN->+5V,
    pin 11->~LDAC). No shorts, no schematic-parity errors.
    [x0x - midi daughter schematic.brd]
